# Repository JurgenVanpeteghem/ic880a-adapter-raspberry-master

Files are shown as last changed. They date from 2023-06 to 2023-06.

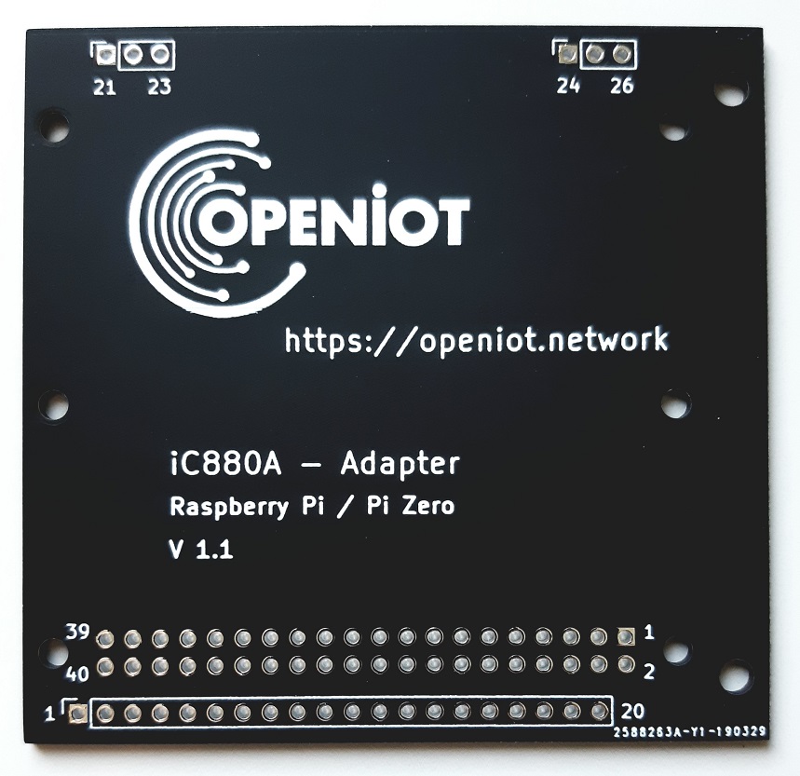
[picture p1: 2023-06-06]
Pictures/iC880A_Adapter_V1.1_1.jpg

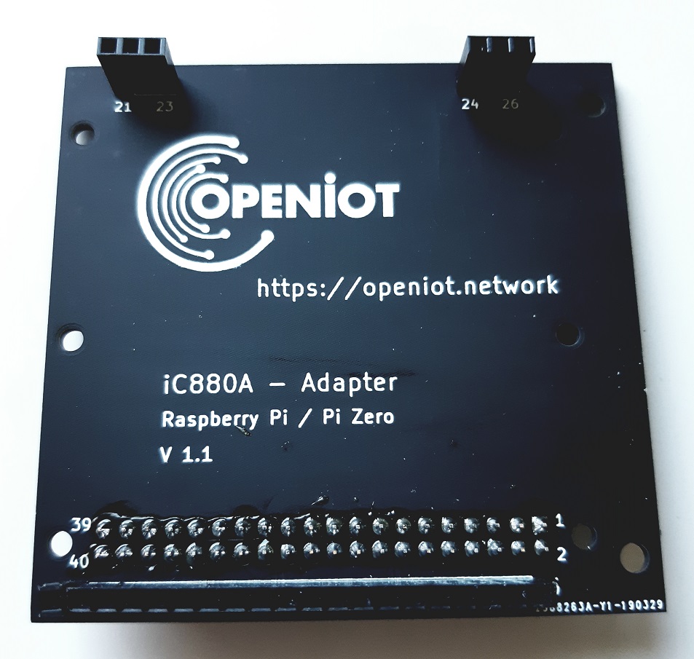
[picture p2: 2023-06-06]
Pictures/iC880A_Adapter_V1.1_3.jpg

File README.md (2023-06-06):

What is it?
-----------
This adapter board connects a Raspberry Pi (Zero, 2 Model B or above) to an IMST iC880A LoRaWAN concentrator board.  
You can use the board instead of jumper wires which makes the work much easier.  
Power is provided by Raspberry Pi.

What you find here
------------------
- KiCad Fils
- Gerber Files
- Pictures of the iC880A-Adapter-Board

iC880A-Adapter-Board
--------------------
It is easy to build the board. You need to solder the following parts to complete it:
- 1 pc of 1x20 pinheader
- 1 pc of 2x20 pinheader
- 2 pcs of 1x3 pinheader

Pinout
------
iC880A <-> Raspberry Pi
- 07 <-> 38 ... GPIO20
- 08 <-> 36 ... GPIO16
- 09 <-> 32 ... GPIO12
- 10 <-> 31 ... GPIO6
- 11 <-> 29 ... GPIO5
- 13 <-> 22 ... GPIO25-Reset
- 14 <-> 23 ... GPIO11-CLK
- 15 <-> 21 ... GPIO9-MISO
- 16 <-> 19 ... GPIO10-MOSI
- 17 <-> 24 ... GPIO8-NSS
- 21 <-> 02 ... 5V-VCC

LoRaWAN-Gateway
---------------
To build a LoRaWAN-Gateway you need just a
- Raspberry Pi (Zero, 2 Model B or above) + power supply
- this iC880A-Adapter-Board
- IMST iC880A LoRaWAN concentrator board
- antenna + cable

Setup the LoRaWAN-Gateway
-------------------------
To set up the software on your LoRaWAN-Gateway, see setup scripts at https://github.com/OpenIotNetwork/ic880a-setup-scripts

Info
----
You find information about our LoRaWAN initiative at https://openiot.network  
See also OpenIoT-Forum at https://forum.openiot.network/t/openiot-ic880a-adapter-board/112

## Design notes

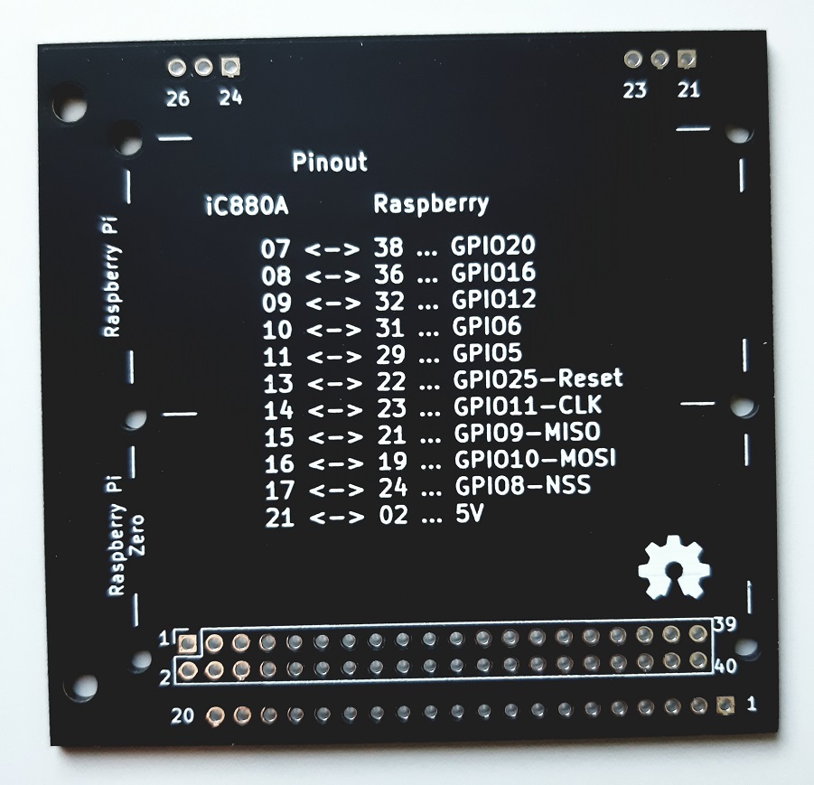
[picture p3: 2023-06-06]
Pictures/iC880A_Adapter_V1.1_2.jpg

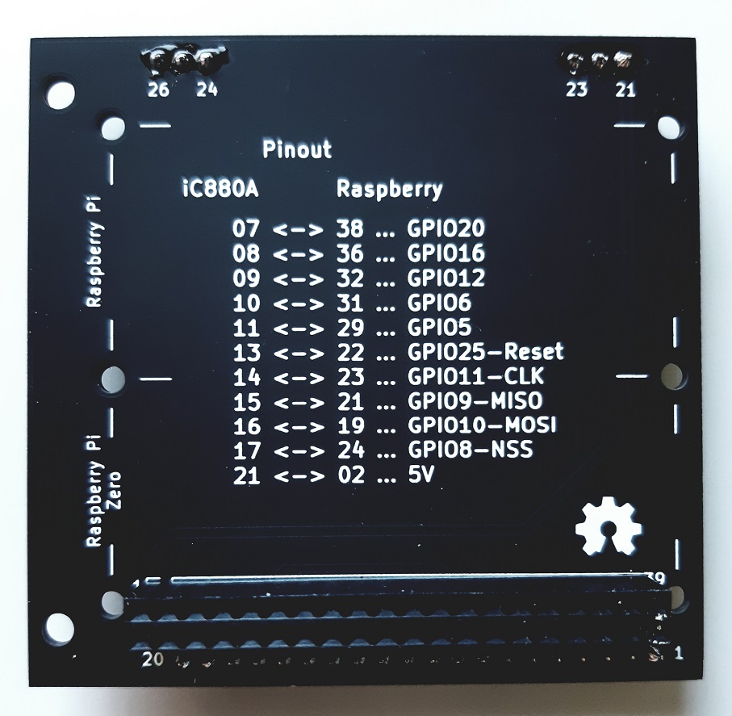
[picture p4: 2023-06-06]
Pictures/iC880A_Adapter_V1.1_4.jpg

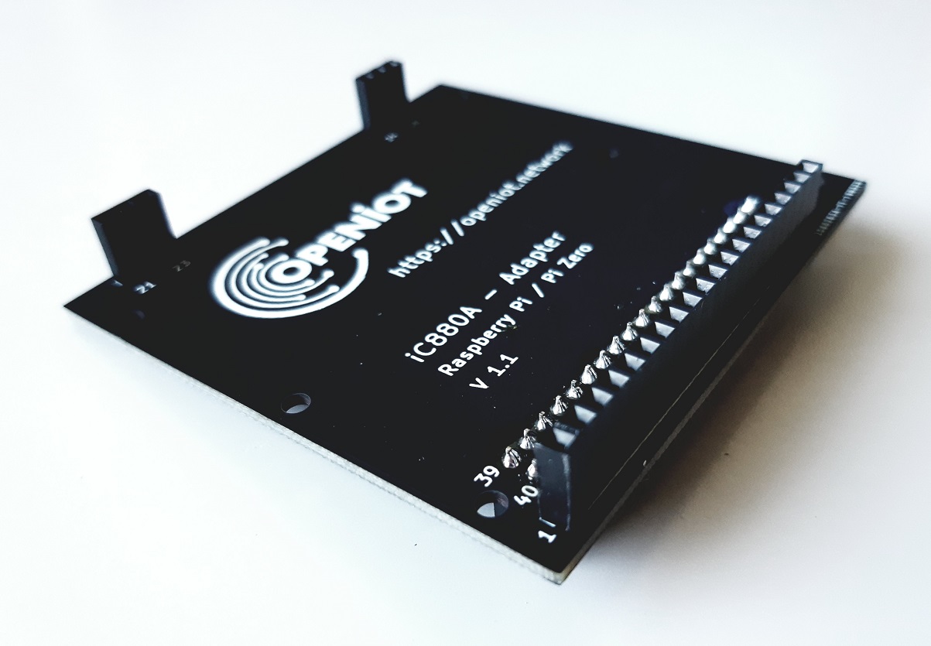
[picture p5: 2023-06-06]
Pictures/iC880A_Adapter_V1.1_5.jpg

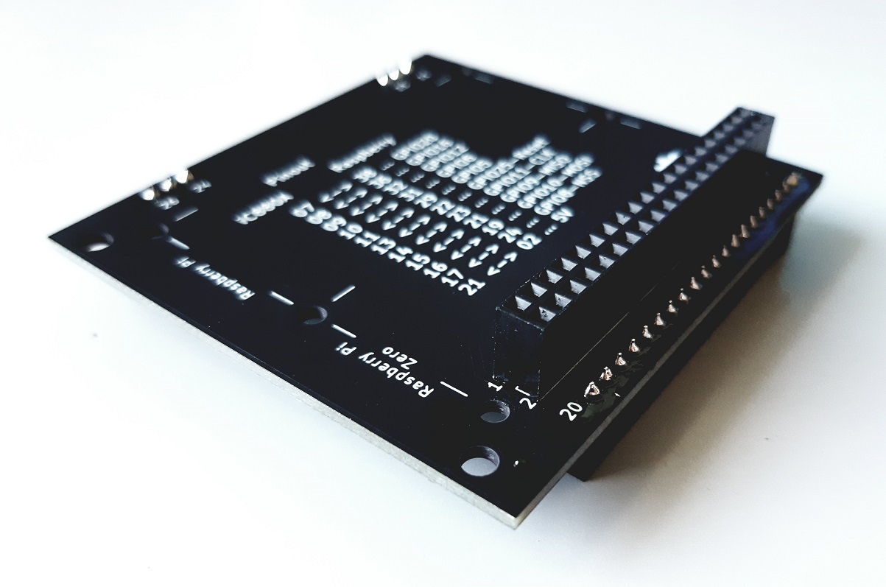
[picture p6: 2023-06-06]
Pictures/iC880A_Adapter_V1.1_6.jpg

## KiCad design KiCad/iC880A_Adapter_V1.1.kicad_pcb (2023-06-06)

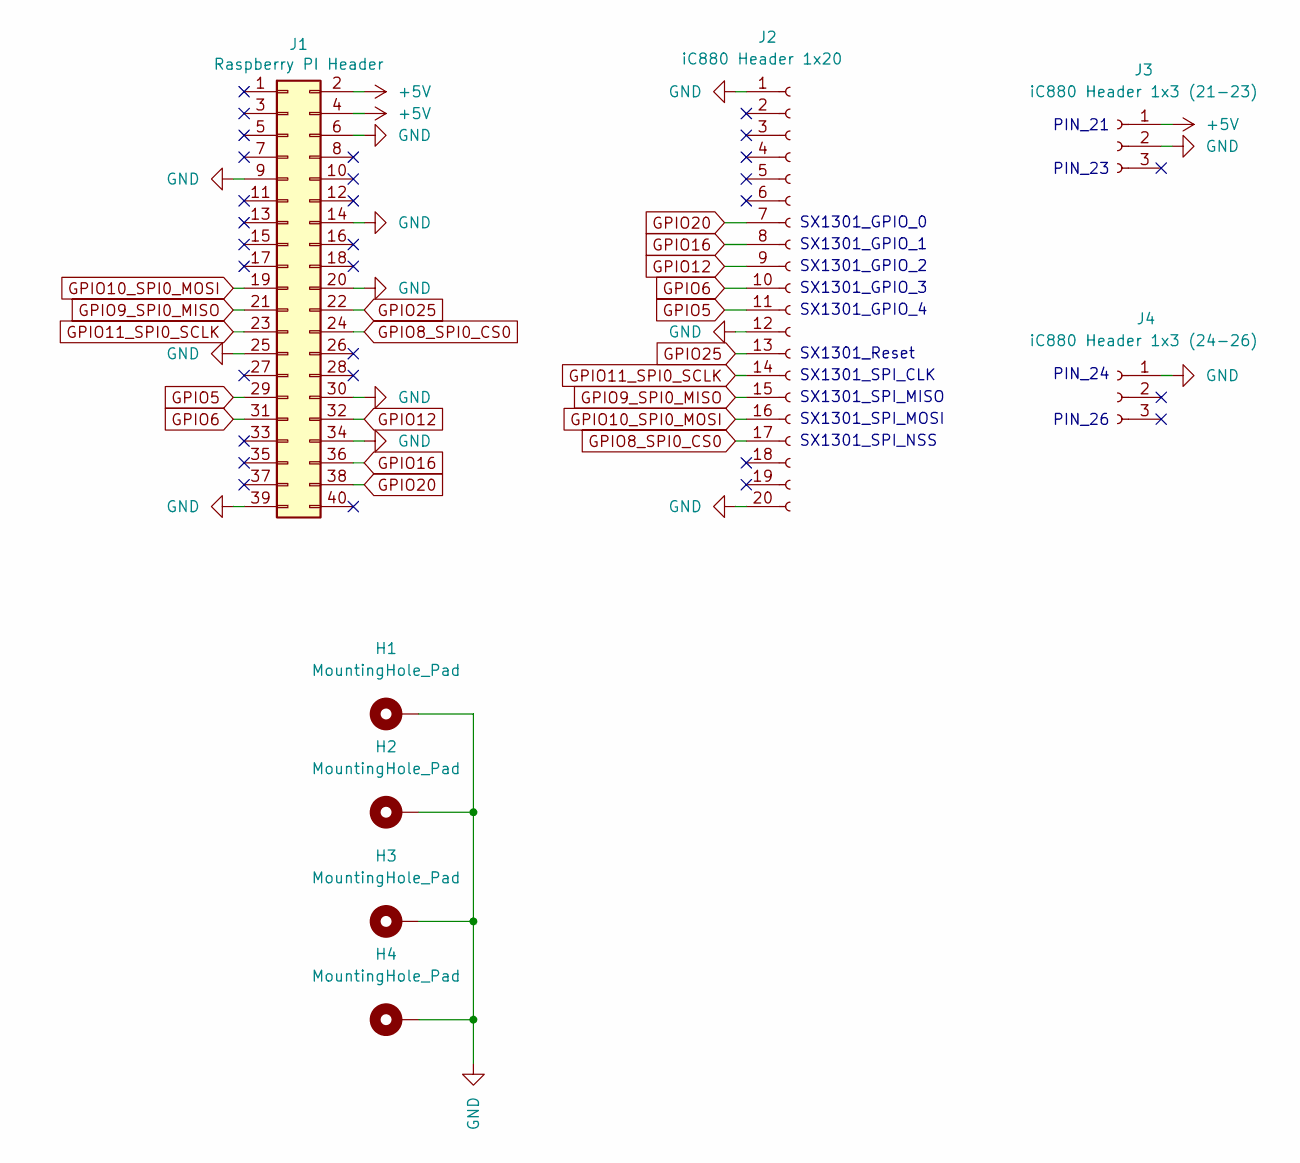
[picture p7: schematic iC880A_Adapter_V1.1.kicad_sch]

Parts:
H1, H2, H3, H4: MountingHole_Pad; MountingHole_3.2mm_M3_ISO7380_Pad
J1: Raspberry PI Header; PinSocket_2x20_P2.54mm_Vertical
J2: iC880 Header 1x20; PinSocket_1x20_P2.54mm_Vertical
J3: iC880 Header 1x3 (21-23); PinSocket_1x03_P2.54mm_Vertical
J4: iC880 Header 1x3 (24-26); PinSocket_1x03_P2.54mm_Vertical

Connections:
+5V: J1.2, J1.4, J3.1
GND: H1.1, H2.1, H3.1, H4.1, J1.6, J1.9, J1.14, J1.20, J1.25, J1.30, J1.34, J1.39, J2.1, J2.12, J2.20, J3.2, J4.1
GPIO5: J1.29, J2.11
GPIO6: J1.31, J2.10
GPIO8_SPI0_CS0: J1.24, J2.17
GPIO9_SPI0_MISO: J1.21, J2.15
GPIO10_SPI0_MOSI: J1.19, J2.16
GPIO11_SPI0_SCLK: J1.23, J2.14
GPIO12: J1.32, J2.9
GPIO16: J1.36, J2.8
GPIO20: J1.38, J2.7
GPIO25: J1.22, J2.13

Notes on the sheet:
PIN_24
SX1301_GPIO_2
SX1301_GPIO_4
SX1301_SPI_CLK
SX1301_SPI_MISO
PIN_21
SX1301_GPIO_0
SX1301_GPIO_3
PIN_23
PIN_26
SX1301_SPI_MOSI
SX1301_Reset
SX1301_SPI_NSS
SX1301_GPIO_1

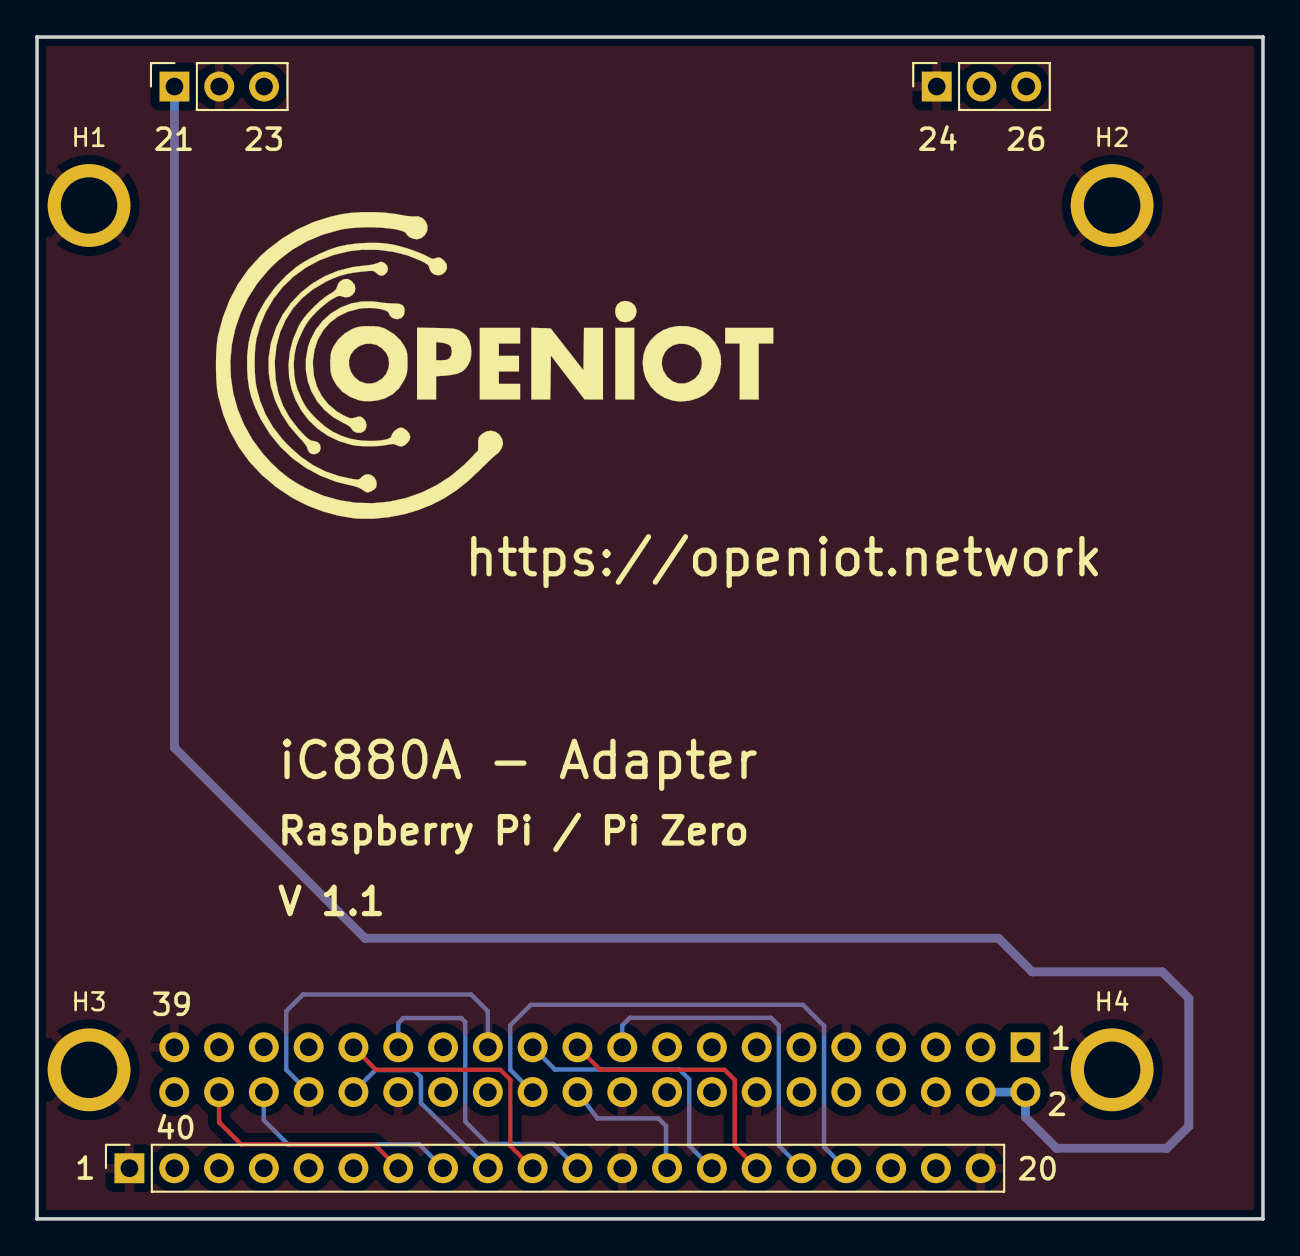
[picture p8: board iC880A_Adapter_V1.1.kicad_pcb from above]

Board: 2 copper layers, 69.5 x 67.0 mm, 8 parts (1 on the bottom side), 12 nets.
